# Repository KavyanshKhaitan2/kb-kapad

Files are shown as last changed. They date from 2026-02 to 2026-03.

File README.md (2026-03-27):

# Kapad
This is a macropad with 16 keys, 16 LEDs, and an OLED display.
# Demo
This has now been built! Go watch the demo over at [YouTube](https://youtu.be/MbUcHhBB-c4)!


# CAD
Two printed parts, made in Fusion360.

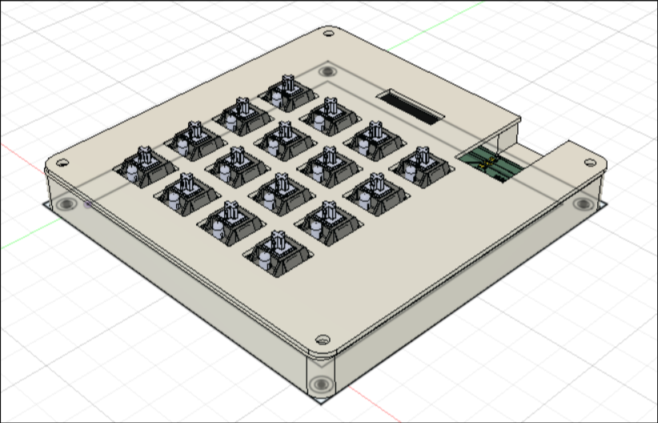
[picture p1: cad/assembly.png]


# PCB
Made using KiCad.
- PCB size: 99.900 x 99.900 mm

Schematic | PCB
:----:|:----:
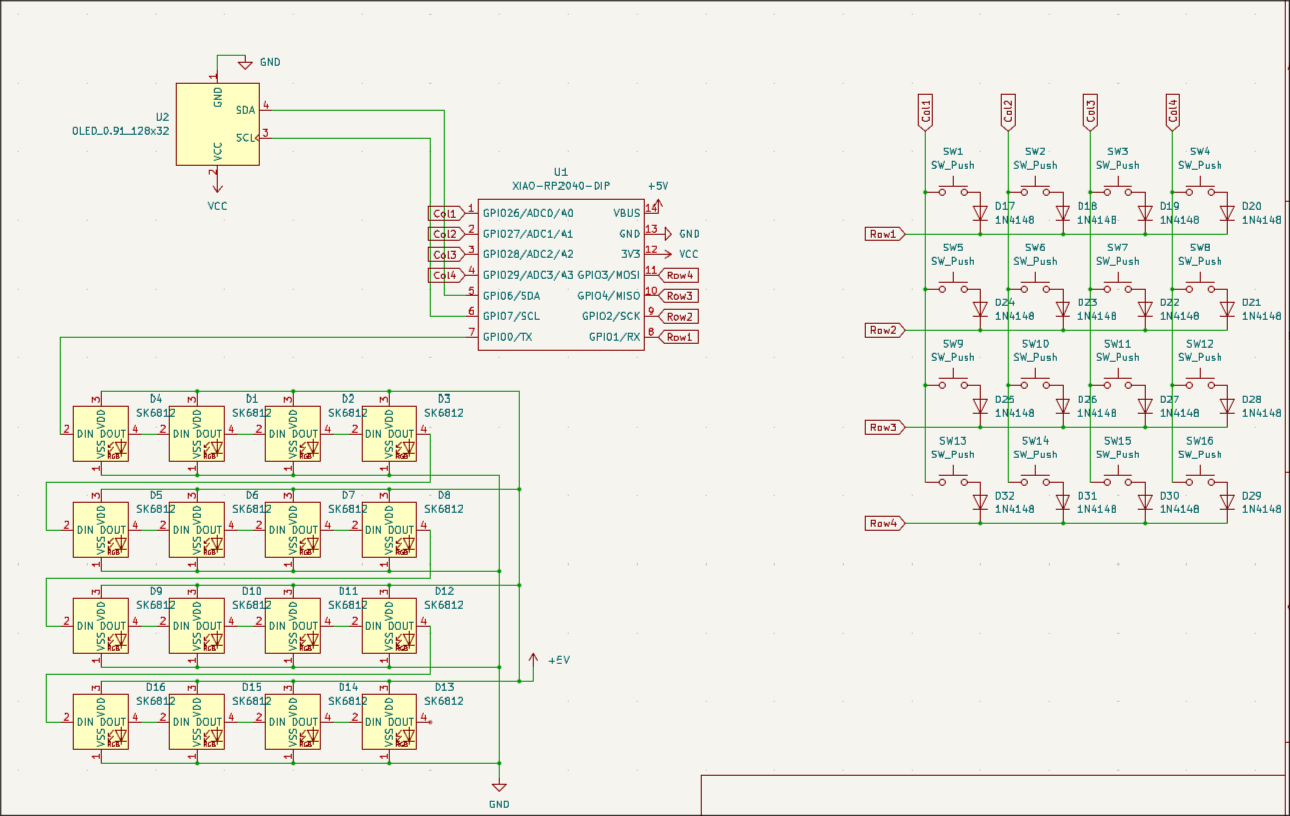
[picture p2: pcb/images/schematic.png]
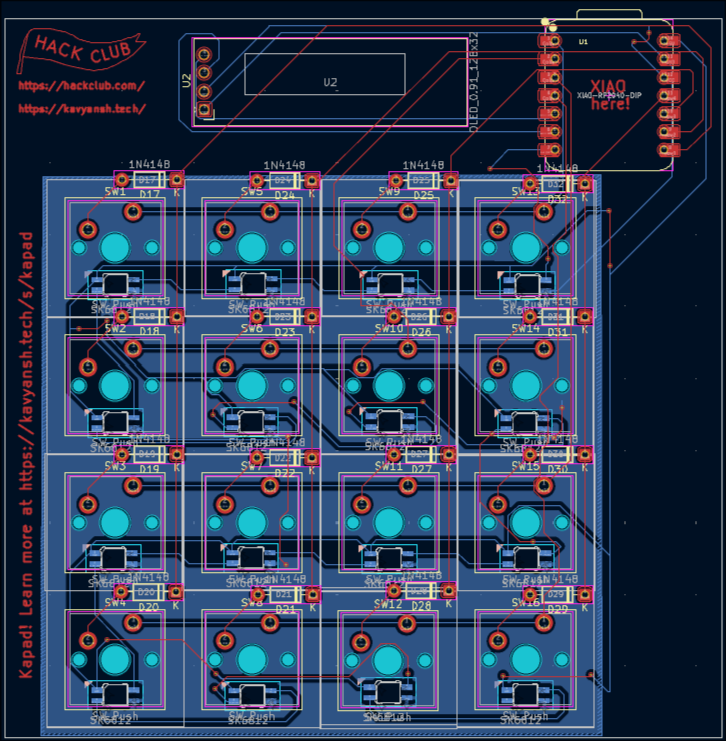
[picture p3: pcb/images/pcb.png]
 | 

# BOM
Bill of Materials:

Qty. | Item
:-:|:-:
16 | Cherry MX Switches
16 | Blank DSA Keycaps
16 | SK6812 MINI LEDs
1 | XIAO RP2040
4 | M3x16 Bolts
4 | M3 Heatset
1 | 3D printed case
4* | Transparent sheet (3x3 cm)

\* I already have this, so I will provide this myself.

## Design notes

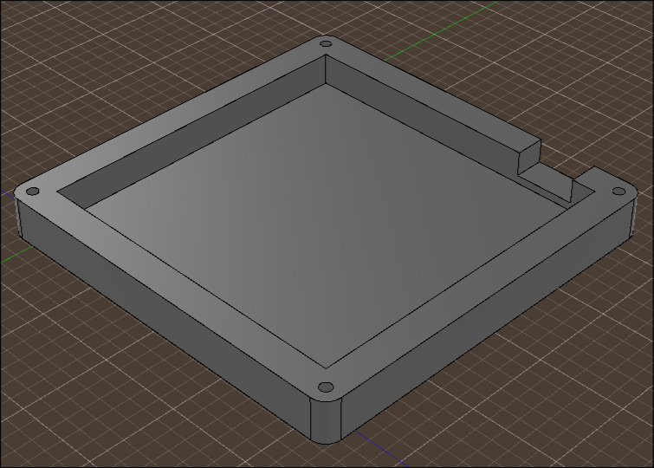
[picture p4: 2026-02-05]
cad/images/bottom_case.png

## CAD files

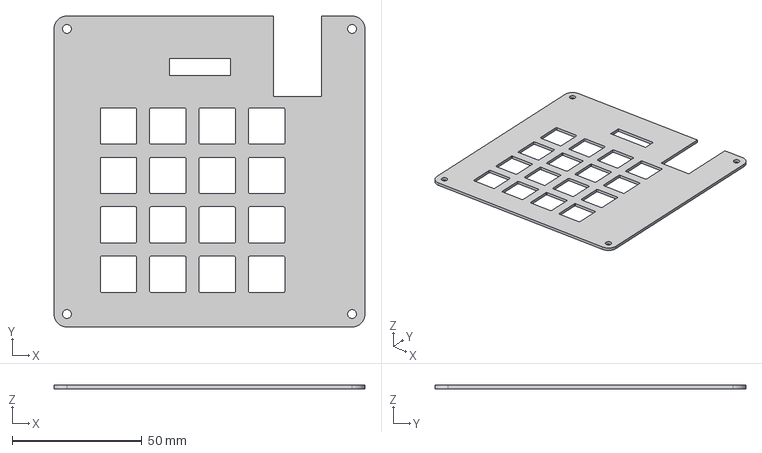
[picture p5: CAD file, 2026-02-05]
cad/files/Top Case.step
119.9 x 119.9 x 1.50 mm

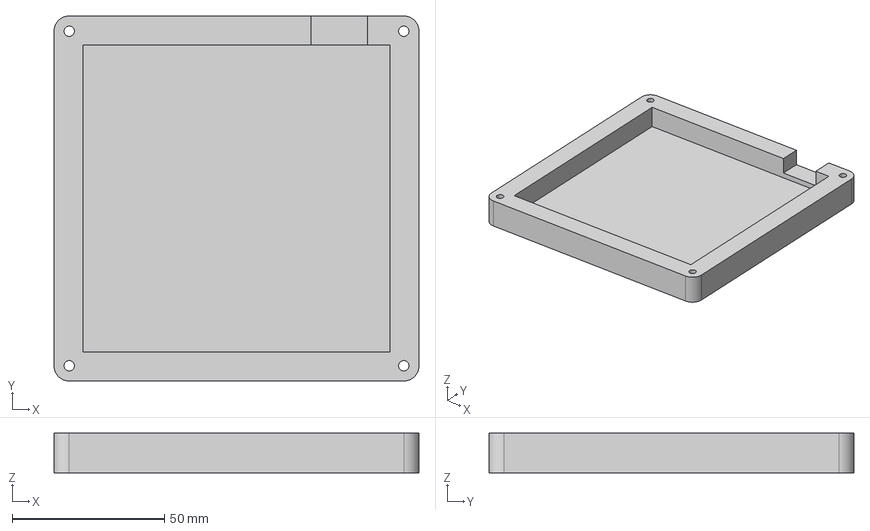
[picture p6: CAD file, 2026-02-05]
cad/files/Bottom Case.step
119.9 x 119.9 x 13.0 mm

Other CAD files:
cad/files/Bottom Case.stl
cad/files/Top Case.stl

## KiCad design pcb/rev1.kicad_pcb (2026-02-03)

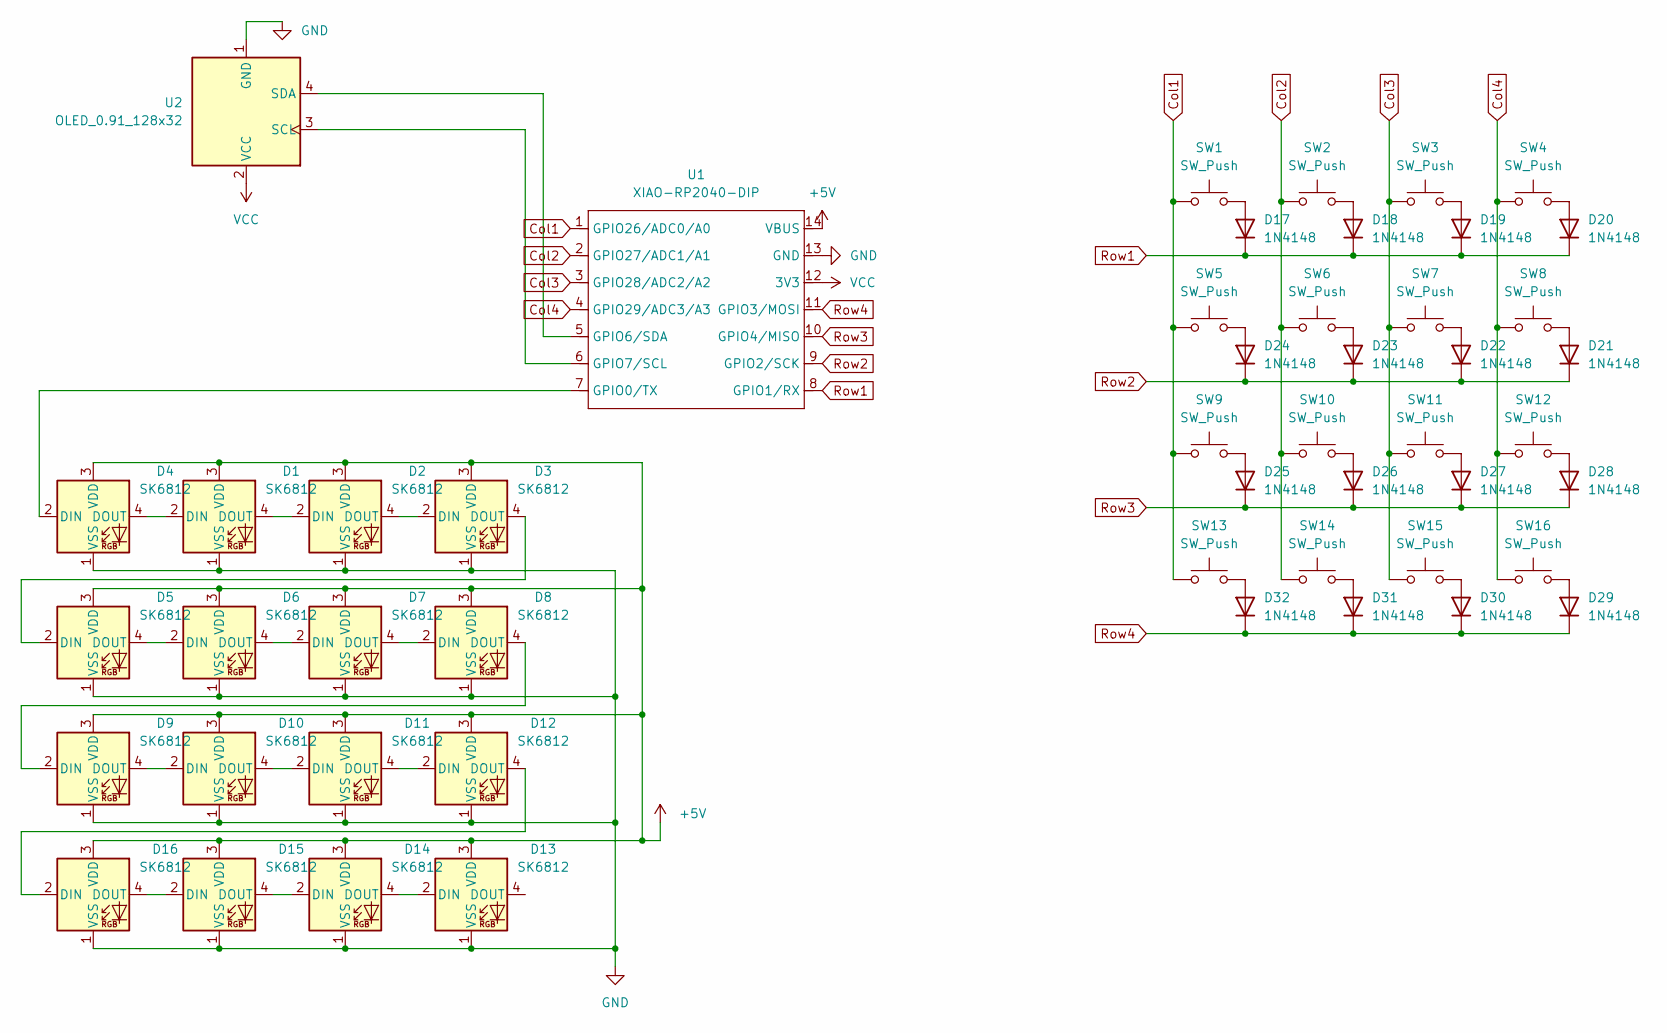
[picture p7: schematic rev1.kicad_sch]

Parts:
D1, D2, D3, D4, D5, D6, D7, D8, D9, D10, D11, D12, D13, D14, D15, D16: SK6812; MX_SK6812MINI-E_REV
D17, D18, D19, D20, D21, D22, D23, D24, D25, D26, D27, D28, D29, D30, D31, D32: 1N4148; D_DO-35_SOD27_P7.62mm_Horizontal
SW1, SW2, SW3, SW4, SW5, SW6, SW7, SW8, SW9, SW10, SW11, SW12, SW13, SW14, SW15, SW16: SW_Push; SW_Cherry_MX_1.00u_PCB
U1: XIAO-RP2040-DIP
U2: OLED_0.91_128x32

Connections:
+5V: D1.3 (VDD), D2.3 (VDD), D3.3 (VDD), D4.3 (VDD), D5.3 (VDD), D6.3 (VDD), D7.3 (VDD), D8.3 (VDD), D9.3 (VDD), D10.3 (VDD), D11.3 (VDD), D12.3 (VDD), D13.3 (VDD), D14.3 (VDD), D15.3 (VDD), D16.3 (VDD), U1.14 (VBUS)
Col1: SW1.1, SW5.1, SW9.1, SW13.1, U1.1 (GPIO26/ADC0/A0)
Col2: SW2.1, SW6.1, SW10.1, SW14.1, U1.2 (GPIO27/ADC1/A1)
Col3: SW3.1, SW7.1, SW11.1, SW15.1, U1.3 (GPIO28/ADC2/A2)
Col4: SW4.1, SW8.1, SW12.1, SW16.1, U1.4 (GPIO29/ADC3/A3)
GND: D1.1 (VSS), D2.1 (VSS), D3.1 (VSS), D4.1 (VSS), D5.1 (VSS), D6.1 (VSS), D7.1 (VSS), D8.1 (VSS), D9.1 (VSS), D10.1 (VSS), D11.1 (VSS), D12.1 (VSS), D13.1 (VSS), D14.1 (VSS), D15.1 (VSS), D16.1 (VSS), U1.13 (GND), U2.1 (GND)
unnamed: D1.2 (DIN), D4.4 (DOUT)
unnamed: D1.4 (DOUT), D2.2 (DIN)
unnamed: D2.4 (DOUT), D3.2 (DIN)
unnamed: D3.4 (DOUT), D5.2 (DIN)
unnamed: D4.2 (DIN), U1.7 (GPIO0/TX)
unnamed: D5.4 (DOUT), D6.2 (DIN)
unnamed: D6.4 (DOUT), D7.2 (DIN)
unnamed: D7.4 (DOUT), D8.2 (DIN)
unnamed: D8.4 (DOUT), D9.2 (DIN)
unnamed: D9.4 (DOUT), D10.2 (DIN)
unnamed: D10.4 (DOUT), D11.2 (DIN)
unnamed: D11.4 (DOUT), D12.2 (DIN)
unnamed: D12.4 (DOUT), D16.2 (DIN)
unnamed: D13.2 (DIN), D14.4 (DOUT)
unnamed: D14.2 (DIN), D15.4 (DOUT)
unnamed: D15.2 (DIN), D16.4 (DOUT)
unnamed: D17.2 (A), SW1.2
unnamed: D18.2 (A), SW2.2
unnamed: D19.2 (A), SW3.2
unnamed: D20.2 (A), SW4.2
unnamed: D21.2 (A), SW8.2
unnamed: D22.2 (A), SW7.2
unnamed: D23.2 (A), SW6.2
unnamed: D24.2 (A), SW5.2
unnamed: D25.2 (A), SW9.2
unnamed: D26.2 (A), SW10.2
unnamed: D27.2 (A), SW11.2
unnamed: D28.2 (A), SW12.2
unnamed: D29.2 (A), SW16.2
unnamed: D30.2 (A), SW15.2
unnamed: D31.2 (A), SW14.2
unnamed: D32.2 (A), SW13.2
unnamed: U1.5 (GPIO6/SDA), U2.4 (SDA)
unnamed: U1.6 (GPIO7/SCL), U2.3 (SCL)
Row1: D17.1 (K), D18.1 (K), D19.1 (K), D20.1 (K), U1.8 (GPIO1/RX)
Row2: D21.1 (K), D22.1 (K), D23.1 (K), D24.1 (K), U1.9 (GPIO2/SCK)
Row3: D25.1 (K), D26.1 (K), D27.1 (K), D28.1 (K), U1.10 (GPIO4/MISO)
Row4: D29.1 (K), D30.1 (K), D31.1 (K), D32.1 (K), U1.11 (GPIO3/MOSI)
VCC: U1.12 (3V3), U2.2 (VCC)

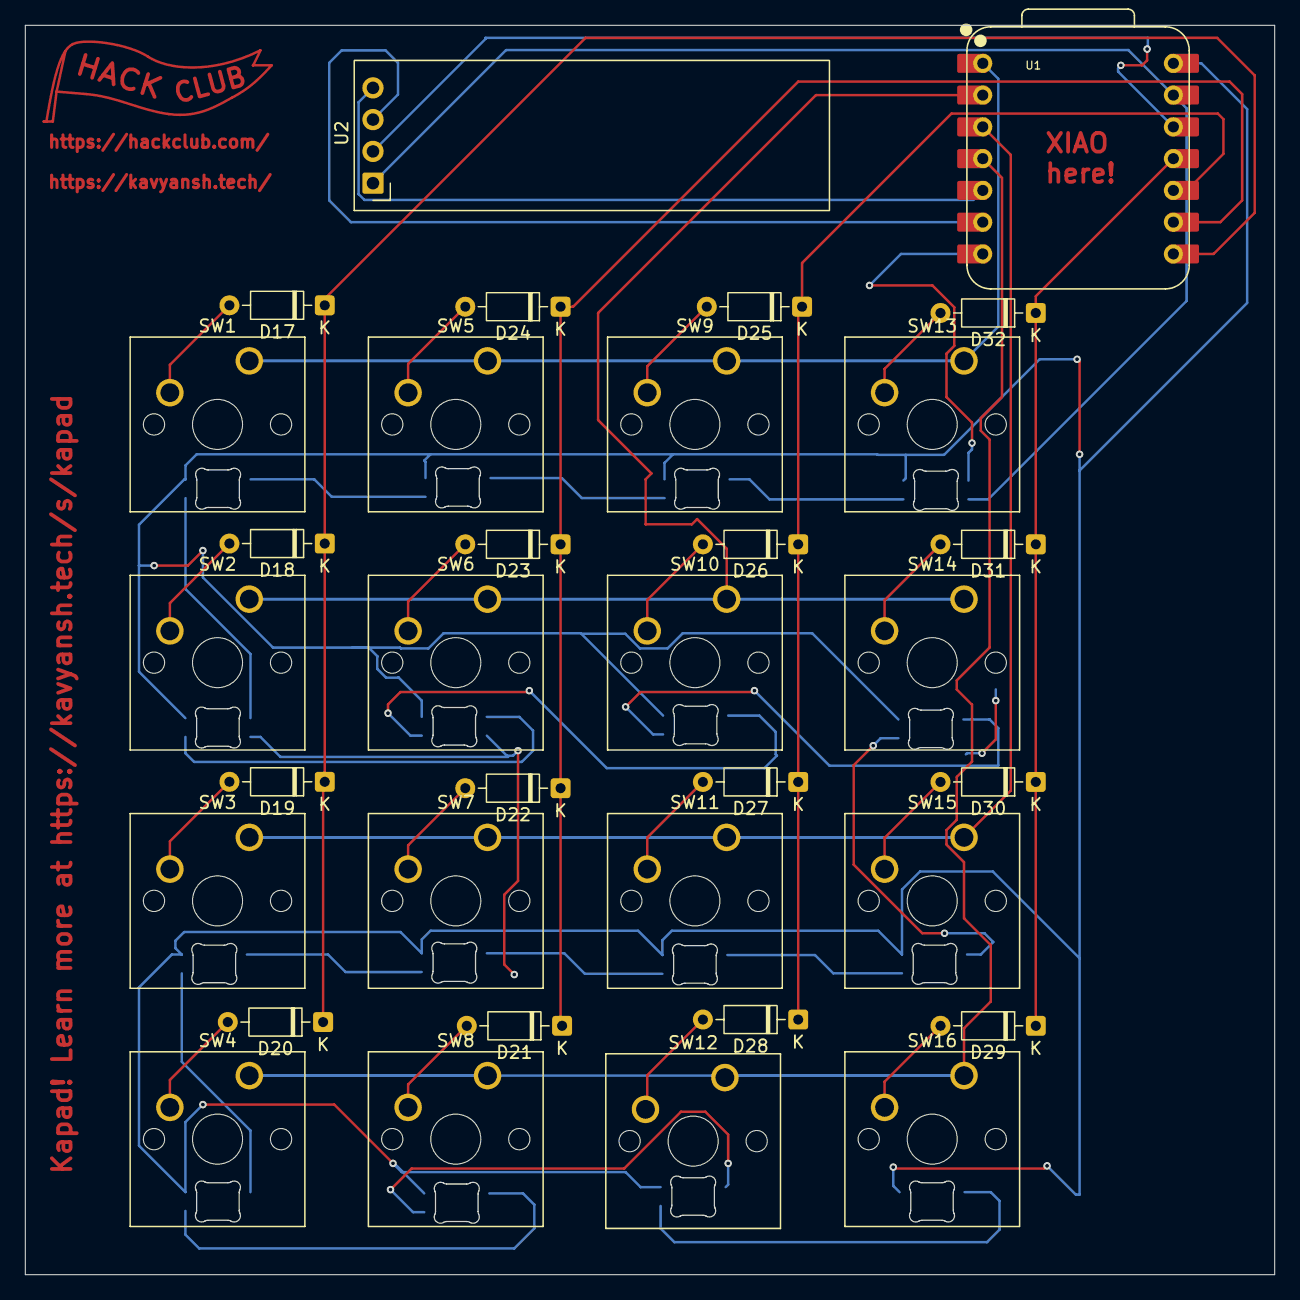
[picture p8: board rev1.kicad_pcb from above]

Board: 2 copper layers, 99.9 x 99.9 mm, 50 parts (0 on the bottom side), 45 nets.

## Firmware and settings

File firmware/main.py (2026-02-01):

# You import all the IOs of your board
import board

# These are imports from the kmk library
from kmk.kmk_keyboard import KMKKeyboard
from kmk.scanners.keypad import KeysScanner
from kmk.keys import KC
from kmk.modules.macros import Press, Release, Tap, Macros

# This is the main instance of your keyboard
keyboard = KMKKeyboard()

# Add the macro extension
macros = Macros()
keyboard.modules.append(macros)

# Define your pins here!
PINS = [board.D3, board.D4, board.D2, board.D1]

# Tell kmk we are not using a key matrix
# keyboard.matrix = KeysScanner(
#     pins=PINS,
#     value_when_pressed=False,
# )

keyboard.col_pins = [board.GP26, board.GP27, board.GP28, board.GP29]
keyboard.row_pins = [board.GP1, board.GP2, board.GP3, board.GP4]

# Here you define the buttons corresponding to the pins
# Look here for keycodes: https://github.com/KMKfw/kmk_firmware/blob/main/docs/en/keycodes.md
# And here for macros: https://github.com/KMKfw/kmk_firmware/blob/main/docs/en/macros.md
keyboard.keymap = [
    [KC.Macro(Press(KC.LALT), Tap(KC.F4), Release(KC.LALT)),],
    [KC.F13],
    [KC.F14],
    [KC.F15],
    [KC.F16],
    [KC.F17],
    [KC.F18],
    [KC.F19],
    [KC.F20],
    [KC.F21],
    [KC.F22],
    [KC.F23],
    [KC.F24],
    [KC.MACRO("BONK!")],
    [KC.MACRO(":pf:")],
    [KC.MACRO(":skulk:")]
]

# Start kmk!
if __name__ == '__main__':
    keyboard.go()

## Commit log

2026-02-01 Added cad, firmware, and pcb
    [rev1.kicad_pcb, rev1.kicad_sch]
2026-02-01 Update README.md
    Updated project details and added sections for CAD, PCB, and BOM.
2026-02-01 Fixed LED footprint
    [rev1.kicad_pcb, rev1.kicad_sch]
2026-02-03 Fixed LEDs not getting power
    [rev1.kicad_pcb, rev1.kicad_sch]
2026-02-05 Added STL files
    [Bottom Case.step, Bottom Case.stl, Top Case.step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]
